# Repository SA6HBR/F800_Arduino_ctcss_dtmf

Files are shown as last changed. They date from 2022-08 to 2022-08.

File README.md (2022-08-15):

# Ericsson F800 with arduino ctcss encoder / decoder and dtmf decoder

Delar av kod har jag bland annat hittat/plockat från:
YO3HJV, ON4ADI & ON7EQ samt Tim Eckel

Funktionsbeskrivning av elektroniken:   
* En färdig LM317-modul för stabilisera drivspänningen från F800 behöver ett par extra kondensatorer för att inte Arduinon skall störas.  
* En LM324 op samt lågpassfiler för ingående subton. Valet av komponenter får en bryt frekvens 153hz. fc= 1/(2πRC) 47nF 22k  
* Arduinon skapar en fyrkantsvåg som subton och ett låpassfilter görom den till sinus. Valet av komponenter får en bryt frekvens 159hz. fc= 1/(2πRC) 100R 10uF  
* Komponenterna är mer valda av vad som ligger på hyllan än 100% rätt.   

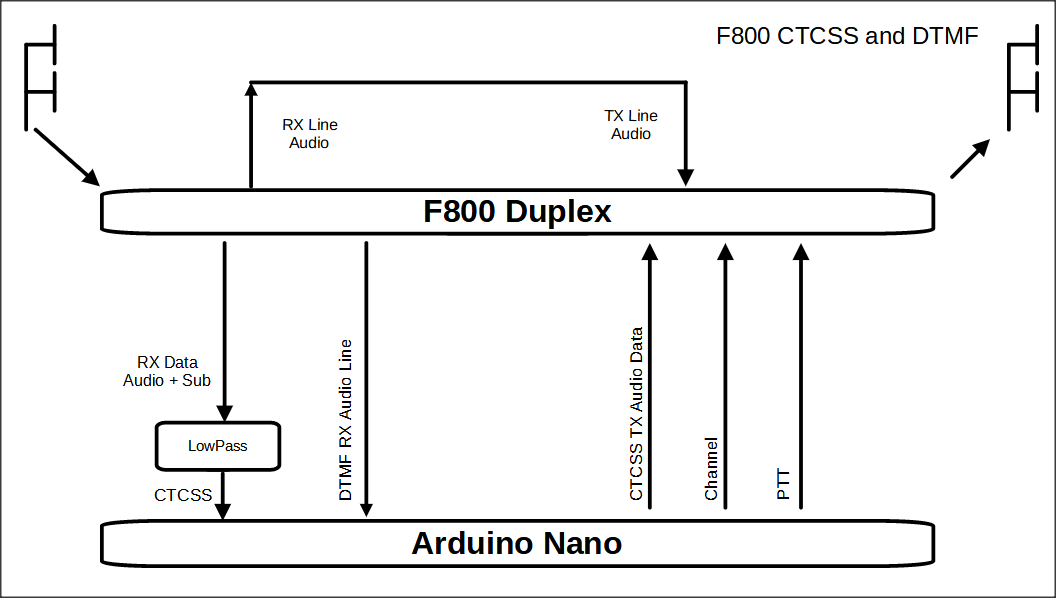
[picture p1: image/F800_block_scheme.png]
block scheme
  
Blockschema. AudioLine är ljud över 300hz och det kopplas direkt mellan RX till TX.  
Från RX AudioData kommer även subtonen och via lp-filter samt op med riktigt hög förstärkning, så bir det en fyrkantsvåg som Arduinon avkodar. 
 
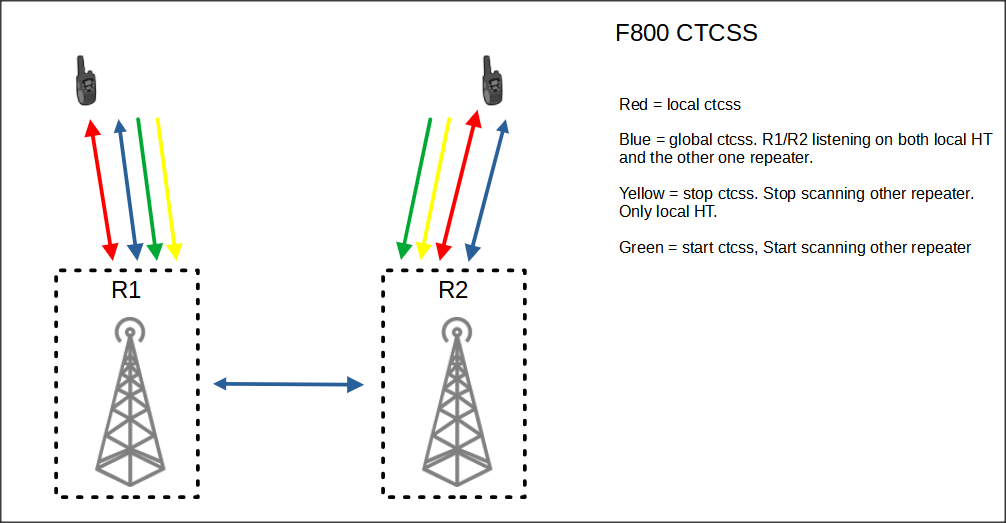
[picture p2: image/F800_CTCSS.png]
CTCSS
  
Som exempel kan man styra funktioner och kanaler med olika subtoner. Koppla samman repetrar som kör på en viss subton. 
 
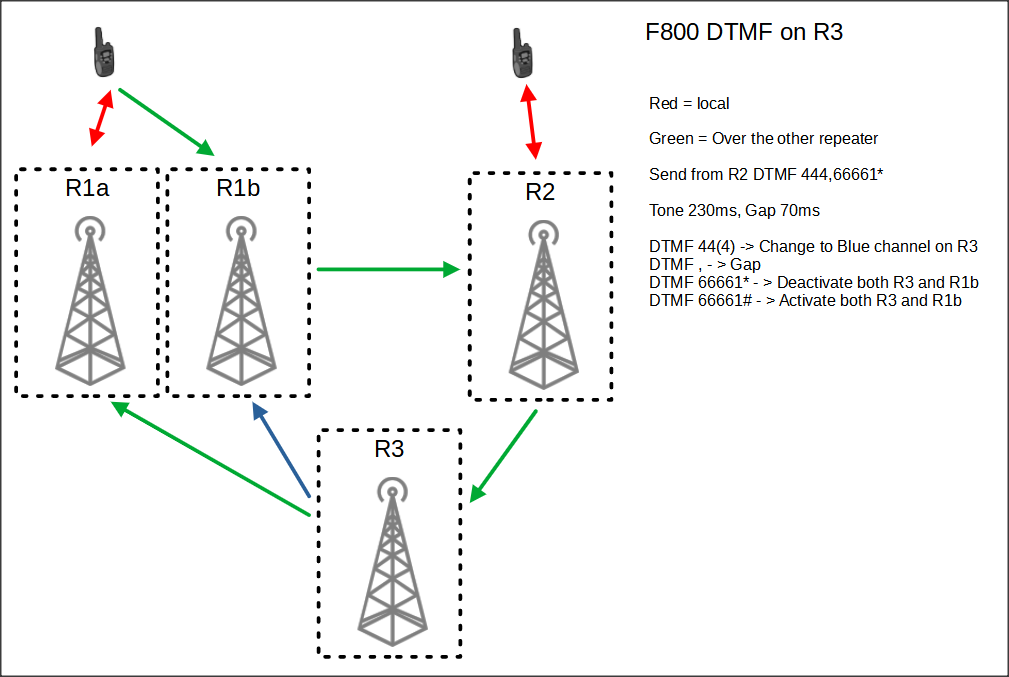
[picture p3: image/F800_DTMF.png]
DTMF
  
Via dtmf kan man också styrafunktioner. Avkoda ton på 130ms om man har 70ms mellan dem. 
Missar ibland första tonen om man kör på så korta toner, så förslagsvis har man första siffra dubbelt och i koden bortser från det.  
 
## Useful Links
* [Circuit Diagram](https://github.com/SA6HBR/F800_Arduino_ctcss/blob/main/KiCad/CircuitDiagram.pdf)
* [Arduino Nano Pinout](https://github.com/SA6HBR/F800_Arduino_ctcss/blob/main/Arduino/ArduinoNanoPinout.pdf)
* [Arduino code for CTCSS](https://github.com/SA6HBR/F800_Arduino_ctcss/blob/main/Arduino/F800_Arduino_ctcss/F800_Arduino_ctcss.ino)
* [Arduino code for DTMF](https://github.com/SA6HBR/F800_Arduino_ctcss/blob/main/Arduino/F800_Arduino_dtmf/F800_Arduino_dtmf.ino)
* [F800 hardware](http://komradio.com/f800.html)

## License

GNU General Public License v3.0, see [LICENSE](https://github.com/SA6HBR/F800_Arduino_ctcss/blob/main/LICENSE) for details.

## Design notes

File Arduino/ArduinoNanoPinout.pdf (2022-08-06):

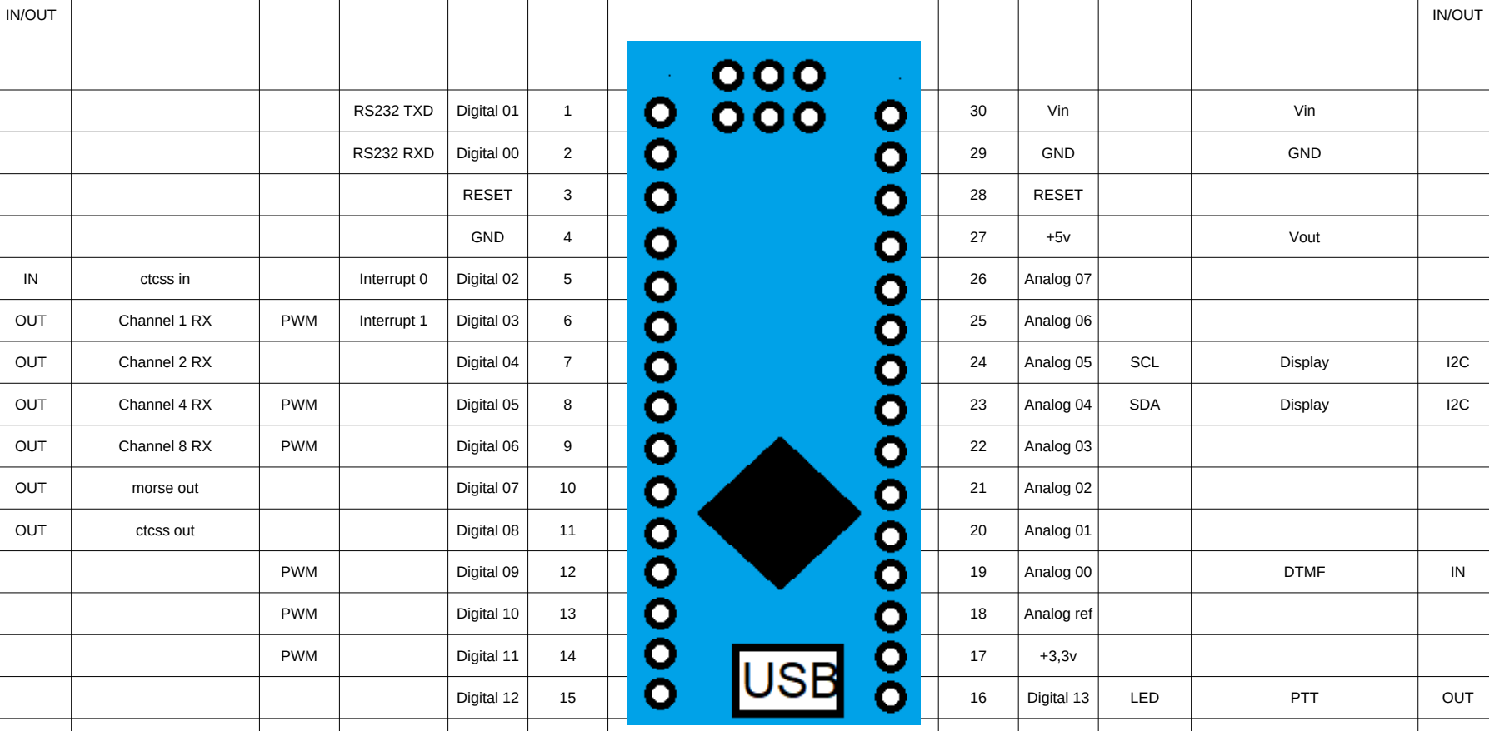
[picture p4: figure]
IN/OUT; RS232 TXD; Digital 01; Vin; RS232 RXD; Digital 00; GND; RESET; Vout; ctcss in; Interrupt 0; Digital 02; Analog 07; OUT; Channel 1 RX; PWM; Interrupt 1; Digital 03; Analog 06; Channel 2 RX; Digital 04; Analog 05; SCL; Display; Channel 4 RX; Digital 05; Analog 04; SDA; Channel 8 RX; Digital 06; Analog 03; morse out; Digital 07; Analog 02; ctcss out; Digital 08; Analog 01; Digital 09; Analog 00; DTMF; Digital 10; Analog ref; Digital 11; Digital 12; Digital 13; LED; PTT

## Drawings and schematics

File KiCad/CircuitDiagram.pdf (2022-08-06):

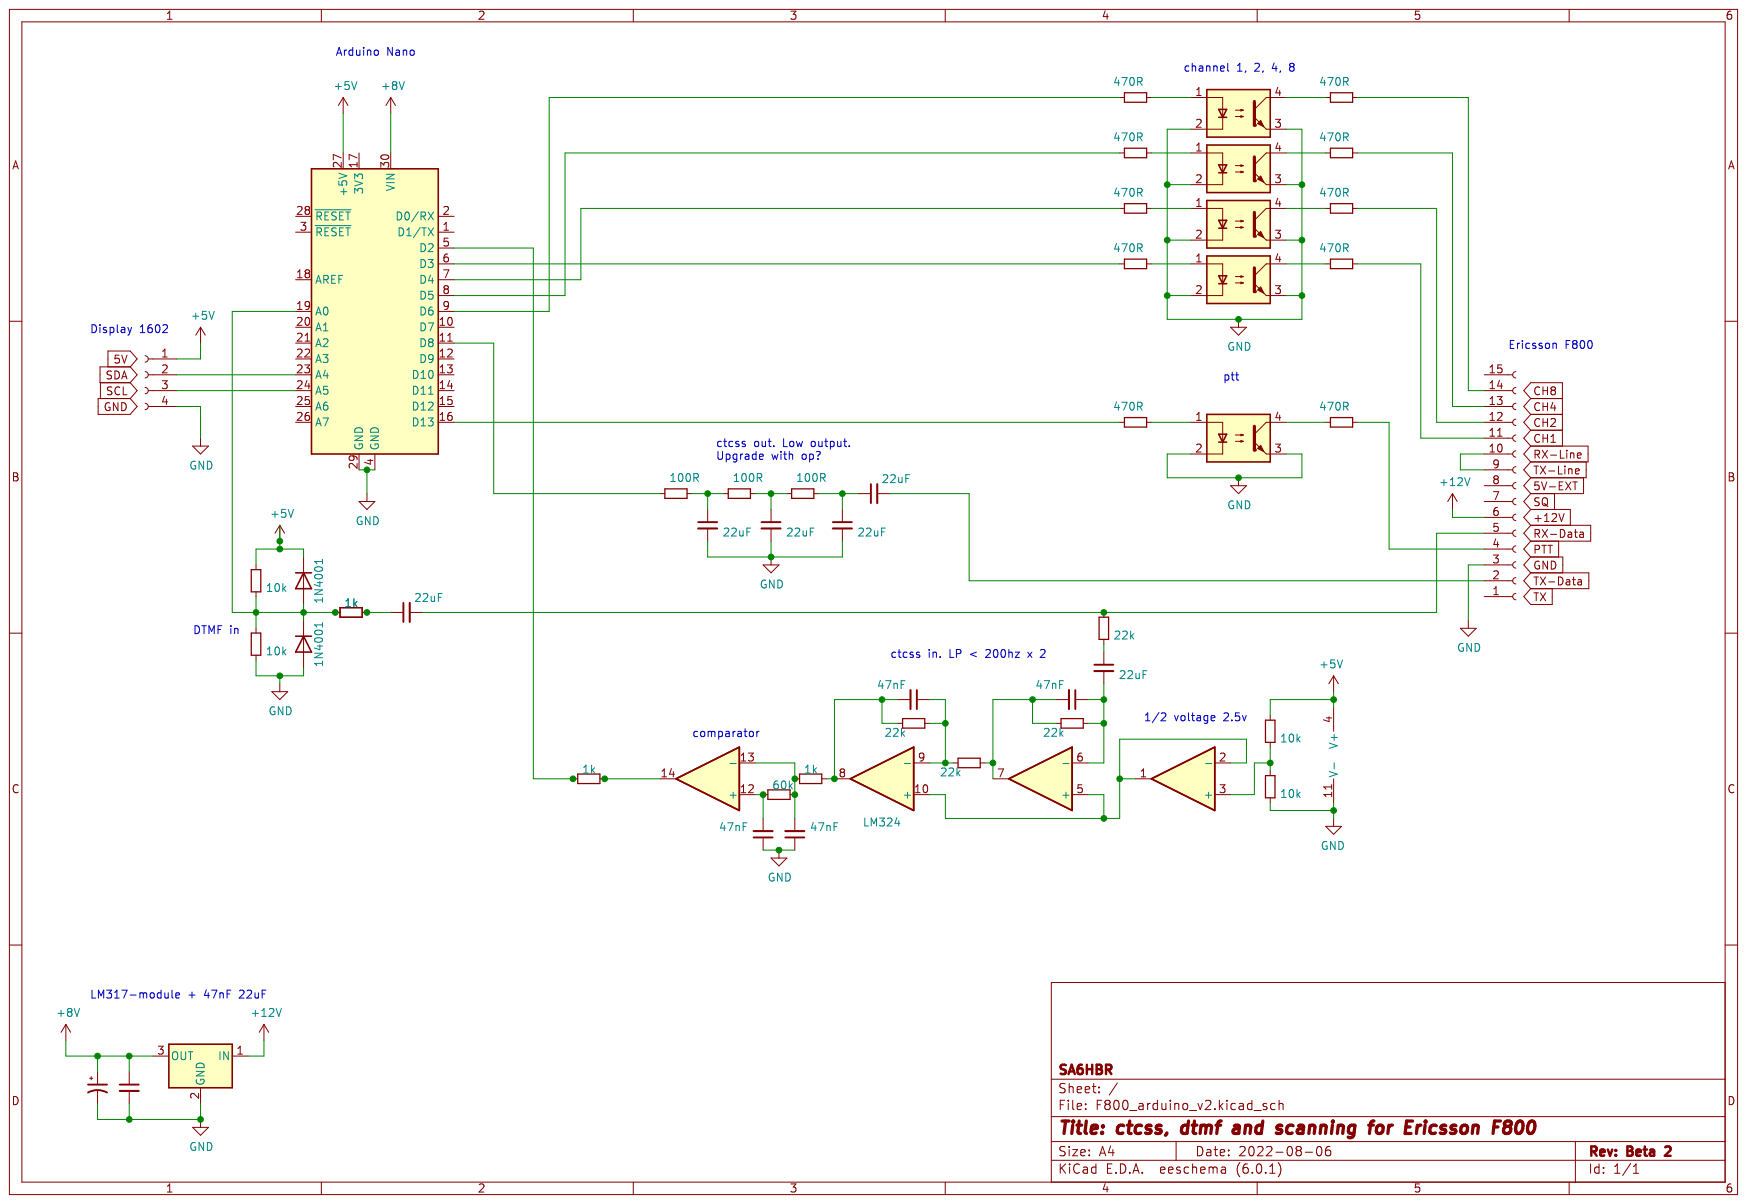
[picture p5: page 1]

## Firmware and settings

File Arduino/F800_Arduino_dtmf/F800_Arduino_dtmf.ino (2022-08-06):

////////////////////////////////////////////////////////////////////////////////////////////////////////////////////////////////////
//
//  CTCSS for Ericson F80X by SA6HBR
// https://github.com/SA6HBR


#include <LiquidCrystal_I2C.h>
#include <NewTone.h>
#include <Goertzel.h>


LiquidCrystal_I2C lcd(0x27,16,2);

////////////////// HARDWAREINFO ////////////////////////////////////////////////////////////////////////////////////////////////////
// SM4EGB
// http://komradio.com/f800.html
// Ericson F802 F804

////////////////// Goertzel ////////////////////////////////////////////////////////////////////////////////////////////////////
// https://github.com/jacobrosenthal/Goertzel
//  The Goertzel algorithm is long standing so see 
//  http://en.wikipedia.org/wiki/Goertzel_algorithm for a full description.
//  It is often used in DTMF tone detection as an alternative to the Fast 
//  Fourier Transform because it is quick with low overheard because it
//  is only searching for a single frequency rather than showing the 
//  occurrence of all frequencies.
//  
//  This work is entirely based on the Kevin Banks code found at
//  http://www.embedded.com/design/configurable-systems/4024443/The-Goertzel-Algorithm 
//  so full credit to him for his generic implementation and breakdown. I've
//  simply massaged it into an Arduino library. I recommend reading his article
//  for a full description of whats going on behind the scenes.
//
//  Created by Jacob Rosenthal, June 20, 2012.
//  Released into the public domain.

//////////////////  CTCSS OUT  /////////////////////////////////////////////////////////////////////////////////////////////////////
//
// AUTHOR/LICENSE:
// Created by Tim Eckel - teckel@leethost.com
// Copyright 2013 License: GNU GPL v3 http://www.gnu.org/licenses/gpl-3.0.html
//
// LINKS:
// Project home: https://bitbucket.org/teckel12/arduino-new-tone/wiki/Home
//
// SYNTAX:
//   NewTone( pin, frequency [, length ] ) - Play a note on pin at frequency in Hz.
//     Parameters:
//       * pin        - Pin speaker is wired to (other wire to ground, be sure to add an inline 100 ohm resistor).
//       * frequency  - Play the specified frequency indefinitely, turn off with noNewTone().
//       * length     - [optional] Set the length to play in milliseconds. (default: 0 [forever], range: 0 to 2^32-1)
//   noNewTone(pin)   - Stop playing note (pin is optional, will always stop playing on pin that was last used).

//////////////////  CTCSS IN ///////////////////////////////////////////////////////////////////////////////////////////////////////
//  YO3HJV, ON4ADI & ON7EQ
//  https://www.qsl.net/on7eq/projects/arduino_ctcss.htm
//
//////////////////  PARAMETERS WHICH CAN BE FINETUNED FOR OPTIMAL DECODING  /////////////////////////////////////////////////////////
//  Decoding of a CTCSS in presence of a signal properly modulated with a CTCSS subtone is no problem and can be easily implemented.
//  The challenge is however NOT TO DECODE in a random manner CTCSS in case of no RF signal, when only noise is present from the dicriminator output.
//  The sketch below includes a waveform analysis performed during the sampling period, to determine if a 'clean' CTCSS is present or not.
//  Some latitude is however permitted to take into account flutter, short spikes, interaction with voice modulation  etc. and still indicate a
//  stable and reliable CTCSS tone.

//  The parameters below allow to finetune the detection in accordance with CTCSS tone(s) to be detected.

//  If parameters are set too stringent, decoding will not be assured in a realiable manner in presence of voice signals
//  If parameters are not set 'tight' enough, stray decoding of 'FRIEND' CTCSS wil occur in presence of noise (signal from discriminator output)

//  the sketch allows decode of 'FRIEND' and 'FOE' CTCSS

//  Adjust the audio level fed to LPF and signal conditioner (making square waves out of sine) to a point where a reliable detection of highest desired CTCSS is possible, 
//  and in the noise the number of 'valid decodes' is 0 or 1, sometimes 2, but does not exceed 2.  Increasing further the audio level (valid decodes > 2) will only increase 
//  the risk of random decodes.  Normally, in preesence of only noise, maximum 1 stray decode of FRIEND CTCSS will occur per hour. 


volatile unsigned long ctcssBand = 10;  // This is +/- % allowed error in waveform format detected, to filter out noise (ideally , waveform should be a pure square wave)
                                        // Do not set too low or decoding will not be possible when voice signals are present

float validdecodes = 50;                // This is the % of valid CTCSS waveforms decoded in one sampling period, required to eliminate spikes & random decode in noise

int filterMinCtcss =  70;               // Lowest  CTCSS frequency to decode. This will set a spikes filter and prevent false decode in noise  
int filterMaxCtcss = 160;               // Highest CTCSS frequency to decode. This will set a spikes filter and prevent false decode in noise  

volatile unsigned long counter = 0;
volatile unsigned long oddEven = 0;
volatile unsigned long startStopOk = 0;
volatile unsigned long secondLastStartStopOk = 0;
volatile unsigned long startStopTime = 0;
volatile unsigned long lastOddTime = 0;
volatile unsigned long secondLastOddTime = 0;
volatile unsigned long lastEvenTime = 0;
volatile unsigned long numPeriodesOk = 0;
volatile unsigned long totalTimeOk = 0;
volatile unsigned long periodTimeMinus = 0;
volatile unsigned long periodTimePlus = 0;
volatile unsigned long periodTime = 0;

float result = 0;
float freq = 0.0;

volatile unsigned long low_passF  = 0;
volatile unsigned long high_passF = 0;

////////////////////////////////////////////////////////////////////////////////////////////////////////////////////////////////////
// SA6HBR

// ctcss array no
//  0,  1,  2,  3,  4,  5,  6,  7,  8,  9, 
// 10, 11, 12, 13, 14, 15, 16, 17, 18, 19, 
// 20, 21, 22, 23, 24, 25, 26, 27, 28, 29, 
// 30, 31, 32, 33, 34, 35, 36, 37, 38, 39, 
// 40, 41, 42, 43, 44, 45, 46, 47, 48, 49, 

float ctcss[] = {
 67.0,  69.3,  71.9,  74.4,  77.0,  79.7,  82.5,  85.4,  88.5,  91.5,
 94.8,  97.4, 100.0, 103.5, 107.2, 110.9, 114.8, 118.8, 123.0, 127.3,
131.8, 136.5, 141.3, 146.2, 151.4, 156.7, 159.8, 162.2, 165.5, 167.9,
171.3, 173.8, 177.3, 179.9, 183.5, 186.2, 189.9, 192.8, 196.6, 199.5,
203.5, 206.5, 210.7, 218.1, 225.7, 229.1, 233.6, 241.8, 250.3, 254.1};

// hardware-settings:
int   channelPin[]      = { 3, 4, 5, 6}; // F800 pin for channel
int   ctcssInPin        = 2;
int   ctcssOutPin       = 8;
int   pttPin            = 13;

uint8_t  dtmfInPin      = A0;
int      vtDTMFPin1     = 10;
int      vtDTMFPin2     = 11;

const int   numOfSamles = 100;
const float     maxFreq = 8900;
float       freqDtmf[9] = {1050,697,770,852,941,1209,1336,1477,1633}; //1050 is referens for noise
float  dtmfToneValue[9];
float       dtmfToneMid = 0;
float       dtmfToneMax = 0;
String       dtmfString = "";
String   dtmfLastString = "";
String   dtmfLastButton = "";
String dtmfButtonPressed = "";



char *radioChannelText[] = {"K1", "K2", "K3"}; //F80X Channel-name in display
byte      radioChannel[] = {   1,    2,    3}; //F80X Channel-number
byte     activeChannel[] = {   1,    1,    1}; //F80X Channel-number
int         ctcssForRX[] = {   9,    9,    9}; //ctcss for RX
int         ctcssForTX[] = {  99,    9,    9}; //ctcss for TX
int   channelNo         = 1;//First is 0          

bool active  = false;
bool ptt     = false;
char pttChar = ' ';

unsigned long     pttTime  = 0;    // Time when ptt have to end.
unsigned long     dtmfTime = 0;    // Time when dtmf ends.
unsigned long     hangTime = 3000; //3 * 1000 = 3 seconds, how long time after last active ctcss to ptt off
unsigned long dtmfHangTime = 15000; //15 * 1000 = 15 seconds, how long time after last active dtmf to ptt off
////////////////////////////////////////////////////////////////////////////////////////////////////////////////////////////////////

void setup()

   {

      pinMode( ctcssInPin, INPUT_PULLUP);            //ctcss in
      
      pinMode( channelPin[0], OUTPUT);               //Channel 1
      pinMode( channelPin[1], OUTPUT);               //Channel 2
      pinMode( channelPin[2], OUTPUT);               //Channel 4
      pinMode( channelPin[3], OUTPUT);               //Channel 8
      setRadioChannel(radioChannel[channelNo]);      //set Channel on Radio
      
      pinMode(pttPin, OUTPUT);                       //PTT
      digitalWrite(pttPin, LOW);                     //set PTT off
      
      lcd.init();                                    // Analog pin 4 & 5
      lcd.backlight();
      
      ctcssBand    = ctcssBand * 100;
      validdecodes = validdecodes / 100;
      
      low_passF =   500000  / filterMaxCtcss; // Spikes filter
      high_passF = 1000000  / filterMinCtcss; // Spikes filter

      bootscreen();

      
    }

////////////////////////////////////////////////////////////////////////////////////////////////////////////////////////////////////


void loop()   
  {
    //if not active change channel

    if (active == false)
      {
        if (channelNo != 1)
          {channelNo = 1;}
        else 
          {channelNo = 2;
        }
        setRadioChannel(radioChannel[channelNo]);
        writeLcdText(1,"Scanning...");
      }

    //if not active DTMF check ctcss
    if (dtmfTime <= millis())
      {
        dtmfString     = "";
        dtmfLastString = "";
        
        // Check if it is a valid ctcss
        freq = getFrequency(100);
        if (freq >= ctcss[ctcssForRX[channelNo]] - 2 && freq <= ctcss[ctcssForRX[channelNo]] + 2)    
        {
          active   = true;
        }
        else if (pttTime + hangTime <= millis())
        {
          active = false;
        }
        
        
        //Change state for PTT
        if (active != ptt)
        {
          ptt = active;
          if (ptt)
          {
            pttTime  = millis() + dtmfHangTime;
            dtmfTime = millis() + dtmfHangTime;

            if (activeChannel[channelNo] == 1)
            {
              pttChar = 'T';
              digitalWrite(pttPin, HIGH);          
            
              if (ctcssForRX[channelNo] < 50)
              {
                NewTone(ctcssOutPin, ctcss[ctcssForTX[channelNo]], 0);
              }
            }
            else 
            {
              pttChar = 'X';            
            }
            writeLcdText(1,"DTMF: " + dtmfString);
          }
          else
          {
            pttChar = ' ';
            digitalWrite(pttPin, LOW);
            noNewTone(ctcssOutPin);
            lcd.init();
          } 
        }
        writeLcd(0,"HZ", freq, channelNo + 1, pttChar);
      }

    // Check if it is a valid DTMF
    dtmfButtonPressed=getDtmfButton();
    if (dtmfButtonPressed != "")
      {
        dtmfTime = millis() + hangTime;
        pttTime  = millis() + hangTime;
      }

    
    if (dtmfLastButton != dtmfButtonPressed)
      {
        dtmfString = dtmfString + dtmfButtonPressed;
        dtmfLastButton = dtmfButtonPressed;
      }

    // Example of dtmf-code 444 gap 66661*      
    if (dtmfString=="44")
      {
          //Change to channel 0
          digitalWrite(pttPin, LOW);
          channelNo = 0;
          setRadioChannel(radioChannel[channelNo]);
          noNewTone(ctcssOutPin);
          if (ctcssForTX[channelNo] < 50)
          {
            NewTone(ctcssOutPin, ctcss[ctcssForTX[channelNo]], 0);
          }          

          digitalWrite(pttPin, HIGH);
    
          dtmfString = "->";
          writeLcd(0,"HZ", freq, channelNo + 1, pttChar);
      }
    else if (dtmfString=="->4")
      {
        dtmfString="->";
      }
    else if (dtmfString.length()==8) { 
           if (dtmfString=="->66661*")
      {
        //Closed for PTT of channel 1
        activeChannel[1] = 0;
        dtmfString = String("Close:") +  radioChannelText[1];
      }
      else if (dtmfString=="->66661#")
      {
        //Active for PTT of channel 1
        activeChannel[1] = 1;
        dtmfString = String("Open:") +  radioChannelText[1];
      }
      else if (dtmfString=="->66662*")
      {
        //Closed for PTT of channel 2
        activeChannel[2] = 0;
        dtmfString = String("Close:") +  radioChannelText[2];
      }
      else if (dtmfString=="->66662#")
      {
        //Active for PTT of channel 2
        activeChannel[2] = 1;
        dtmfString = String("Open: ") +  radioChannelText[2];
      }
     }

    if (dtmfString!=dtmfLastString)
      {
        dtmfLastString = dtmfString; 
        writeLcdText(1,"DTMF: " + dtmfString);
      }
          
}

////////////////////////////////////////////////////////////////////////////////////////////////////////////////////////////////////
String getDtmfButton(){


int firstTestBegin = 1;
int firstTestEnd   = 4;
int lastTestBegin  = 5;
int lastTestEnd    = 7;

int countTone      = 0;
String dtmfButton  = "";;
int dtmfToneOk     = 0;

  for(int i=firstTestBegin;i<=firstTestEnd;i++)
  {
    dtmfToneValue[i] = getDtmfToneValue(freqDtmf[i]);
    countTone +=1;
    dtmfToneMid += dtmfToneValue[i];
  }
  dtmfToneMid = dtmfToneMid / countTone; 

  for(int i=firstTestBegin;i<=firstTestEnd;i++)
  {
    if (dtmfToneValue[i]>dtmfToneMid && dtmfToneValue[i]>400) 
      {
        dtmfToneOk += 1;
      }
  }

  if (dtmfToneOk==1)
    {
    
      for(int i=lastTestBegin;i<=lastTestEnd;i++)
      {
        dtmfToneValue[i] = getDtmfToneValue(freqDtmf[i]);
      }

      countTone =0;
      dtmfToneMid = 0;

      for(int i=firstTestBegin;i<=lastTestEnd;i++)
        {
          countTone +=1;
          dtmfToneMid += dtmfToneValue[i];
        }
      dtmfToneMid = dtmfToneMid / countTone;
   
      if (dtmfToneValue[1]>dtmfToneMid)
        {    
          if (dtmfToneValue[5]>dtmfToneMid) {dtmfButton=dtmfButton+"1";}
          if (dtmfToneValue[6]>dtmfToneMid) {dtmfButton=dtmfButton+"2";}
          if (dtmfToneValue[7]>dtmfToneMid) {dtmfButton=dtmfButton+"3";}
          if (dtmfToneValue[8]>dtmfToneMid) {dtmfButton=dtmfButton+"A";}
        }
      
      if (dtmfToneValue[2]>dtmfToneMid)
        {
          if (dtmfToneValue[5]>dtmfToneMid) {dtmfButton=dtmfButton+"4";}
          if (dtmfToneValue[6]>dtmfToneMid) {dtmfButton=dtmfButton+"5";}
          if (dtmfToneValue[7]>dtmfToneMid) {dtmfButton=dtmfButton+"6";}
          if (dtmfToneValue[8]>dtmfToneMid) {dtmfButton=dtmfButton+"B";}
        }
      
      if (dtmfToneValue[3]>dtmfToneMid)
        {
          if (dtmfToneValue[5]>dtmfToneMid) {dtmfButton=dtmfButton+"7";}
          if (dtmfToneValue[6]>dtmfToneMid) {dtmfButton=dtmfButton+"8";}
          if (dtmfToneValue[7]>dtmfToneMid) {dtmfButton=dtmfButton+"9";}
          if (dtmfToneValue[8]>dtmfToneMid) {dtmfButton=dtmfButton+"C";}
        }
      
      if (dtmfToneValue[4]>dtmfToneMid)
        {
          if (dtmfToneValue[5]>dtmfToneMid) {dtmfButton=dtmfButton+"*";}
          if (dtmfToneValue[6]>dtmfToneMid) {dtmfButton=dtmfButton+"0";}
          if (dtmfToneValue[7]>dtmfToneMid) {dtmfButton=dtmfButton+"#";}
          if (dtmfToneValue[8]>dtmfToneMid) {dtmfButton=dtmfButton+"D";}
        }
        
        if (dtmfButton.length()>1) {dtmfButton="";}
    }

  return dtmfButton;
}

float getDtmfToneValue(float freq){
  Goertzel goertzel = Goertzel(freq, numOfSamles, maxFreq);
  goertzel.sample(dtmfInPin); 
  return goertzel.detect();
}


void setRadioChannel(byte channel)
{
  for (int i =0;i<4;i++)
  {
    if (bitRead(channel, i)==1)
    {
      digitalWrite(channelPin[i], HIGH);
    }
    else
    {
      digitalWrite(channelPin[i], LOW);
    }
  }  
  delay(50);
}

void writeLcd(byte row, String text1, float _freq, byte channel, char text2 )
  {
    lcd.setCursor(1, row);
    lcd.print (text1);
    lcd.print("   ");
    int pos = 5;
    if (round(_freq*100) > 9999){pos -=1;}
    if (round(_freq*100) >  999){pos -=1;}
    lcd.setCursor(pos, row);
    lcd.print (_freq,2);
    lcd.print(" ");  
    lcd.setCursor(10, row);
    lcd.print("CH ");
    if (channel < 10){lcd.print(" ");}
    lcd.print (channel);
    lcd.print (text2);    
  }
  
void writeLcdText(byte row, String text )
  {
    lcd.setCursor(1, row);
    lcd.print (text);
    lcd.print ("                 ");
  }

void bootscreen()
  {
      writeLcdText(0,"CTCSS for F80X");
      writeLcdText(1,"*** SA6HBR ***");
      delay(5000);
  }
  
////////////////////////////////////////////////////////////////////////////////////////////////////////////////////////////////////


float getFrequency(unsigned int sampleTime)   

   {                                           // START OF getFrequency FUNCTION

   counter = 1;
   totalTimeOk = 0;
   numPeriodesOk = 0;
   attachInterrupt(digitalPinToInterrupt(2), interruptHandlerChange, CHANGE);      
   delay(sampleTime);
   detachInterrupt(digitalPinToInterrupt(2));

   if (totalTimeOk < 40000) {
      result = 0.0;
      }
    else if ((totalTimeOk / numPeriodesOk) < 4000){            // digital filter Low Pass
      result = 0.0;
      }
    else if ((totalTimeOk / numPeriodesOk) > 16000){           // digital filter High Pass
      result = 0.0;
      }  
    else if (numPeriodesOk <= (((counter-1)/2)*validdecodes))   // check how many valid waves in one sample
      {
      result = (0.0);
      }


   else
      {
      result = (1000700.0 * (float)(numPeriodesOk))/(float)(totalTimeOk);
      
// NOTE: 1000700.0 is the value found by me. The theoretic value is "1.000.000,0"
// Start with this value and check the precision against a good frequency meter.
       }
                                                                                                  
   return result;
    }                                             // END OF getFrequency FUNCTION


////////////////////////////////////////////////////////////////////////////////

void interruptHandlerChange()

   {                                  // START OF interruptHandlerChange ROUTINE

   startStopTime = micros();

   if (counter == 1)                  // if counter is 1 : we have to initialize
      {  
      oddEven = 1;
      startStopOk = 2;   
      secondLastStartStopOk = 2;
      lastOddTime = startStopTime;
      secondLastOddTime = startStopTime;
      lastEvenTime = startStopTime;               
      }

   if (oddEven == 1)                    // lets pretend : odd is a rising change
      {
      oddEven = 2;
      startStopOk = 1;

      if (((startStopTime - lastEvenTime) < low_passF))      // Spikes filter
         {
         startStopOk = 2;
         }

      if (((startStopTime - lastOddTime) < (low_passF * 2)))       
         {
         startStopOk = 2;
         secondLastStartStopOk = 2;
         }

      if (((startStopTime - lastOddTime) > high_passF))     // Spikes filter
         {
         startStopOk = 2;
         secondLastStartStopOk = 2;
         }

      lastOddTime = startStopTime;
      }

   else                               // lets pretend : even is a falling change
      {
      oddEven = 1;

      if (((startStopTime - lastOddTime) < low_passF))
         {
         startStopOk = 2;
         }

      if ((startStopOk == 1) && (secondLastStartStopOk == 1)) {

         if (numPeriodesOk == 0)
            {  
            numPeriodesOk++;
            totalTimeOk = totalTimeOk + lastOddTime;
            totalTimeOk = totalTimeOk - secondLastOddTime;
            }

         else
            {
            periodTime = totalTimeOk * ctcssBand;  //  Wave form analysis 
            periodTimeMinus = (totalTimeOk * 10000);
            periodTimePlus = periodTimeMinus;
            periodTimeMinus = (periodTimeMinus - periodTime);
            periodTimePlus = (periodTimePlus + periodTime);
            periodTimeMinus = (periodTimeMinus / numPeriodesOk);
            periodTimePlus = (periodTimePlus / numPeriodesOk); 
            periodTime = (lastOddTime - secondLastOddTime);
            periodTime = (periodTime * 10000);

            if ((periodTime > periodTimeMinus) && (periodTime < periodTimePlus))
               {
               numPeriodesOk++;
               totalTimeOk = totalTimeOk + lastOddTime;
               totalTimeOk = totalTimeOk - secondLastOddTime;
               }
                         
             else {
                if (numPeriodesOk < 3) {
                numPeriodesOk = 1;
                totalTimeOk = lastOddTime - secondLastOddTime;
                }
             }
           } 
         }

      if ( startStopOk == 1 )
         {
         secondLastOddTime = lastOddTime;
         secondLastStartStopOk = startStopOk;
         }

      lastEvenTime = startStopTime;   
      }
 
   counter++;  // debug good decodes

   }                                    // END OF interruptHandlerChange ROUTINE
